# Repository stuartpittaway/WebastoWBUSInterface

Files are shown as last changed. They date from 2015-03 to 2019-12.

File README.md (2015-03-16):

# WebastoWBUSInterface

Hardware circuit and diagram for interfacing to the Webasto WBUS interface from a PC/Arduino

This small circuit allows you to connect a 5 volt device with a serial port to a Webasto Heater which communicates in the WBUS protocol.

The circuit expects you to connect a FT232R USB Serial to TTL interface, or a micro controller such as the Arduino.

Its a http://fritzing.org/home/ circuit/file so you can make a PCB from it if you want (not tested!).

It uses hardly any parts, costs less than £1 (GBP) to make.

Amount 	Part Type 	Properties
1 	Generic female header - 3 pins 	row single; hole size 1.0mm,0.508mm; pin spacing 0.1in (2.54mm); pins 3; form ♀ (female); package THT
3 	NPN-Transistor 	variant variant 2; type NPN (EBC); package TO92 [THT]; part # BC548 NPN
1 	Generic female header - 6 pins 	row single; hole size 1.0mm,0.508mm; pin spacing 0.1in (2.54mm); pins 6; form ♀ (female); package THT; part # FTDI BASIC
1 	Yellow (595nm) LED 	color Yellow (595nm); package 3 mm [THT]; 
1 	PNP-Transistor 	type PNP (CBE); package TO92 [THT]; part # BC557 PNP
4 	10kΩ Resistor 	bands 4; tolerance ±5%; pin spacing 400 mil; resistance 10kΩ; package THT
3 	1kΩ Resistor 	bands 4; tolerance ±5%; pin spacing 400 mil; resistance 1kΩ; package THT

Have fun!

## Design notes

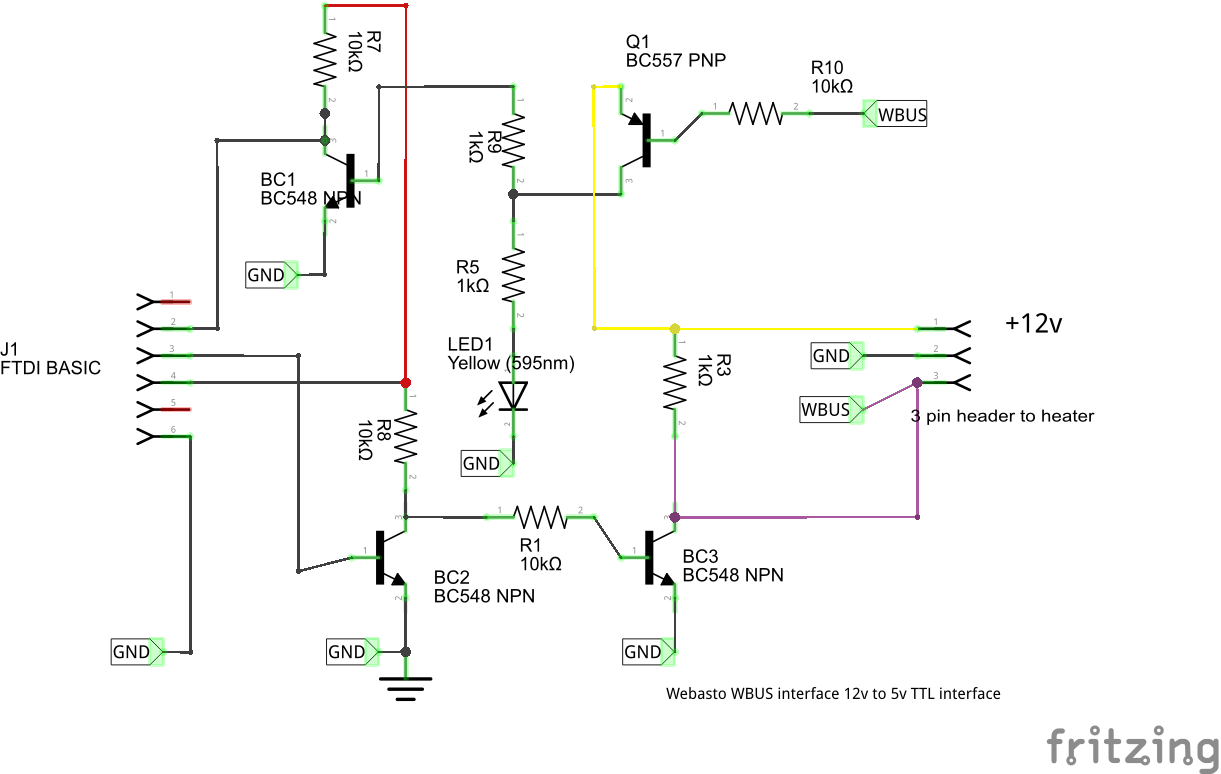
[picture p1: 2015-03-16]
Webasto WBus Arduino Serial Interface mk7_schem.png

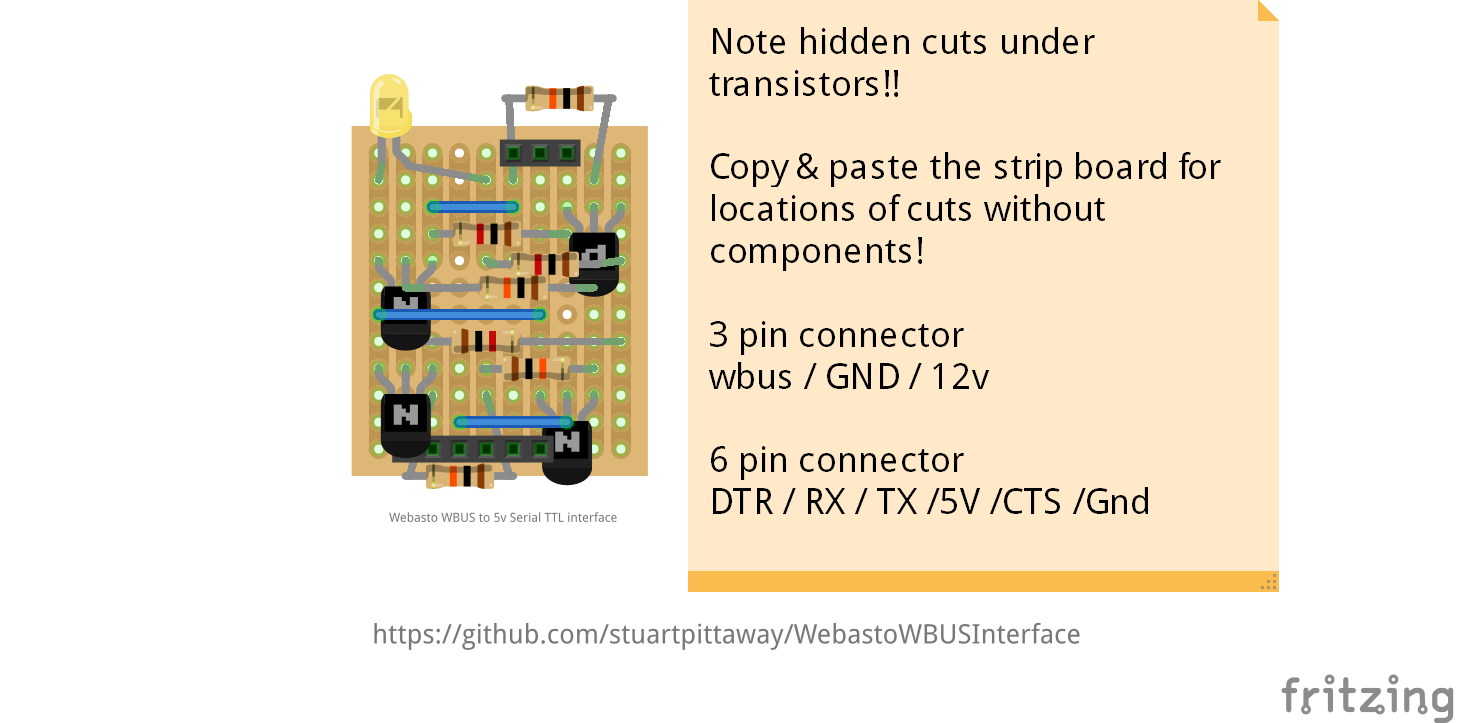
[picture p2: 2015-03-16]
Webasto WBus Arduino Serial Interface mk7_bb.png

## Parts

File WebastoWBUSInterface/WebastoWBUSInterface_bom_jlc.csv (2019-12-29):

Comment | Designator | Footprint | LCSC Part #
LED | D1 | LED_0603_HandSoldering | C72043
S9013 | Q3,Q2,Q1 | SOT-23 | C6749
S9015 | Q4 | SOT-23 | C2149
10K | R1,R8,R10,R7 | R_0805_HandSoldering | C17414
1K | R3,R5,R9 | R_0805_HandSoldering | C17513

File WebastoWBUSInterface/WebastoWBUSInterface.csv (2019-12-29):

Source: | E:\source\WebastoWBUSInterface\WebastoWBUSInterface\WebastoWBUSInterface.sch
Date: | 29/12/2019 22:57:43
Tool: | Eeschema (5.1.0)-1
Generator: | C:\Program Files\KiCad\bin\scripting\plugins/bom_csv_grouped_by_value.py
Component Count: | 14
Individual Components:
Item | Qty | Reference(s) | Value | LibPart | Footprint | Datasheet | JLCPCBPartNumber | Part
 |  | D1 | LED | Device:LED | LEDs:LED_0603_HandSoldering | https://datasheet.lcsc.com/szlcsc/Everlight-Elec-19-217-GHC-YR1S2-3T_C72043.pdf | C72043
 |  | J1 | FTDI Interface | Connector_Generic:Conn_01x06 | Socket_Strips:Socket_Strip_Angled_1x06_Pitch2.54mm | ~
 |  | J2 | WBUS | Connector:Conn_01x03_Female | Connectors_Terminal_Blocks:TerminalBlock_bornier-3_P5.08mm | ~
 |  | Q1 | S9013 | Transistor_BJT:BC548 | TO_SOT_Packages_SMD:SOT-23 | https://datasheet.lcsc.com/szlcsc/Changjiang-Electronics-Tech-CJ-S9015_C2149.pdf | C6749 | S9013
 |  | Q2 | S9013 | Transistor_BJT:BC548 | TO_SOT_Packages_SMD:SOT-23 | https://datasheet.lcsc.com/szlcsc/Changjiang-Electronics-Tech-CJ-S9013_C6749.pdf | C6749 | S9013
 |  | Q3 | S9013 | Transistor_BJT:BC548 | TO_SOT_Packages_SMD:SOT-23 | https://datasheet.lcsc.com/szlcsc/Changjiang-Electronics-Tech-CJ-S9013_C6749.pdf | C6749 | S9013
 |  | Q4 | S9015 | Transistor_BJT:BC557 | TO_SOT_Packages_SMD:SOT-23 | https://datasheet.lcsc.com/szlcsc/Changjiang-Electronics-Tech-CJ-S9015_C2149.pdf | C2149 | S9015
 |  | R1 | 10K | Device:R | Resistors_SMD:R_0805_HandSoldering | https://datasheet.lcsc.com/szlcsc/Uniroyal-Elec-0805W8F1001T5E_C17513.pdf | C17414 | 0805W8F1002T5E
 |  | R3 | 1K | Device:R | Resistors_SMD:R_0805_HandSoldering | https://datasheet.lcsc.com/szlcsc/Uniroyal-Elec-0805W8F1001T5E_C17513.pdf | C17513 | 0805W8F1001T5E
 |  | R5 | 1K | Device:R | Resistors_SMD:R_0805_HandSoldering | https://datasheet.lcsc.com/szlcsc/Uniroyal-Elec-0805W8F1001T5E_C17513.pdf | C17513 | 0805W8F1001T5E
 |  | R7 | 10K | Device:R | Resistors_SMD:R_0805_HandSoldering | https://datasheet.lcsc.com/szlcsc/Uniroyal-Elec-0805W8F1001T5E_C17513.pdf | C17414 | 0805W8F1002T5E
 |  | R8 | 10K | Device:R | Resistors_SMD:R_0805_HandSoldering | https://datasheet.lcsc.com/szlcsc/Uniroyal-Elec-0805W8F1001T5E_C17513.pdf | C17414 | 0805W8F1002T5E
 |  | R9 | 1K | Device:R | Resistors_SMD:R_0805_HandSoldering | https://datasheet.lcsc.com/szlcsc/Uniroyal-Elec-0805W8F1001T5E_C17513.pdf | C17513 | 0805W8F1001T5E
 |  | R10 | 10K | Device:R | Resistors_SMD:R_0805_HandSoldering | https://datasheet.lcsc.com/szlcsc/Uniroyal-Elec-0805W8F1001T5E_C17513.pdf | C17414 | 0805W8F1002T5E
Collated Components:
Item | Qty | Reference(s) | Value | LibPart | Footprint | Datasheet | JLCPCBPartNumber | Part
1 | 1 | D1 | LED | Device:LED | LEDs:LED_0603_HandSoldering | https://datasheet.lcsc.com/szlcsc/Everlight-Elec-19-217-GHC-YR1S2-3T_C72043.pdf | C72043
2 | 1 | J1 | FTDI Interface | Connector_Generic:Conn_01x06 | Socket_Strips:Socket_Strip_Angled_1x06_Pitch2.54mm | ~
3 | 1 | J2 | WBUS | Connector:Conn_01x03_Female | Connectors_Terminal_Blocks:TerminalBlock_bornier-3_P5.08mm | ~
4 | 3 | Q1, Q2, Q3 | S9013 | Transistor_BJT:BC548 | TO_SOT_Packages_SMD:SOT-23 | https://datasheet.lcsc.com/szlcsc/Changjiang-Electronics-Tech-CJ-S9015_C2149.pdf | C6749 | S9013
5 | 1 | Q4 | S9015 | Transistor_BJT:BC557 | TO_SOT_Packages_SMD:SOT-23 | https://datasheet.lcsc.com/szlcsc/Changjiang-Electronics-Tech-CJ-S9015_C2149.pdf | C2149 | S9015
6 | 4 | R1, R7, R8, R10 | 10K | Device:R | Resistors_SMD:R_0805_HandSoldering | https://datasheet.lcsc.com/szlcsc/Uniroyal-Elec-0805W8F1001T5E_C17513.pdf | C17414 | 0805W8F1002T5E
7 | 3 | R3, R5, R9 | 1K | Device:R | Resistors_SMD:R_0805_HandSoldering | https://datasheet.lcsc.com/szlcsc/Uniroyal-Elec-0805W8F1001T5E_C17513.pdf | C17513 | 0805W8F1001T5E

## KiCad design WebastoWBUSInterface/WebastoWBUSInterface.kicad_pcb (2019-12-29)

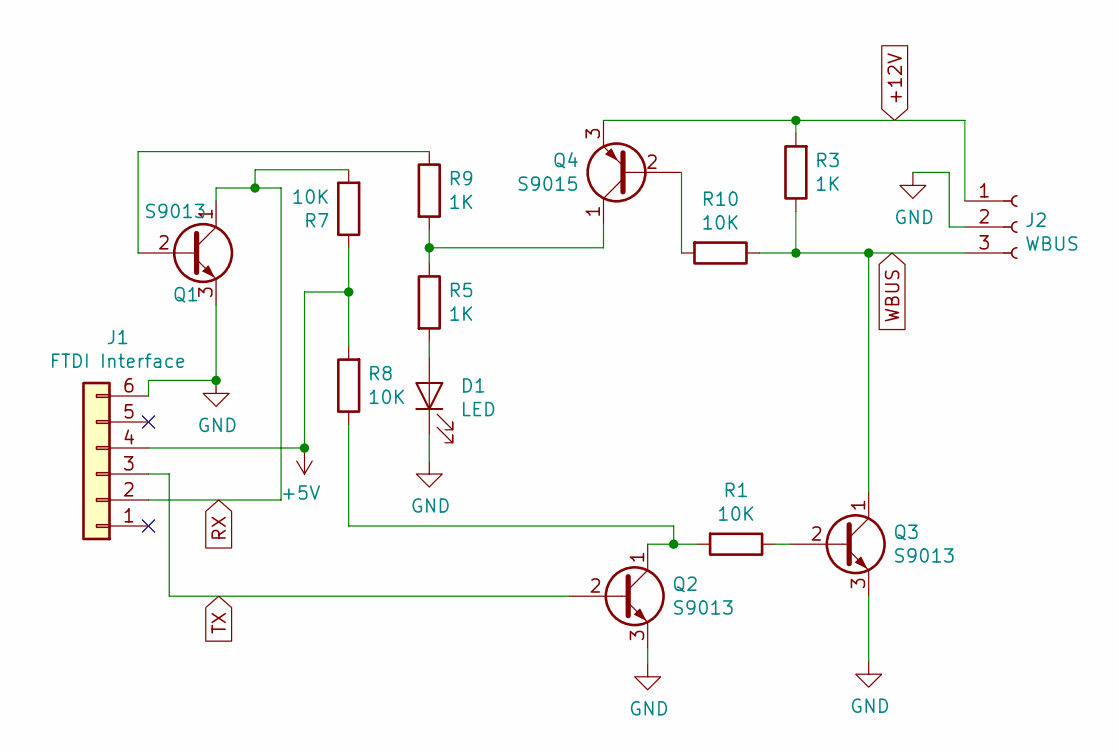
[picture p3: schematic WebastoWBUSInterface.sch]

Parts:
D1: LED; LED_0603_HandSoldering; JLCPCBPartNumber C72043
J1: FTDI Interface; Socket_Strip_Angled_1x06_Pitch2.54mm
J2: WBUS; TerminalBlock_bornier-3_P5.08mm
Q1, Q2, Q3: S9013; SOT-23; Part S9013; JLCPCBPartNumber C6749
Q4: S9015; SOT-23; Part S9015; JLCPCBPartNumber C2149
R1, R7, R8, R10: 10K; R_0805_HandSoldering; Part 0805W8F1002T5E; JLCPCBPartNumber C17414
R3, R5, R9: 1K; R_0805_HandSoldering; Part 0805W8F1001T5E; JLCPCBPartNumber C17513

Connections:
+5V: J1.4, R7.1, R8.2
+12V: J2.1, Q4.3 (E), R3.2
GND: D1.1 (K), J1.6, J2.2, Q1.3 (E), Q2.3 (E), Q3.3 (E)
unnamed: D1.2 (A), R5.2
unnamed: Q1.2 (B), R9.1
unnamed: Q2.1 (C), R1.2, R8.1
unnamed: Q3.2 (B), R1.1
unnamed: Q4.1 (C), R5.1, R9.2
unnamed: Q4.2 (B), R10.2
RX: J1.2, Q1.1 (C), R7.2
TX: J1.3, Q2.2 (B)
WBUS: J2.3, Q3.1 (C), R3.1, R10.1

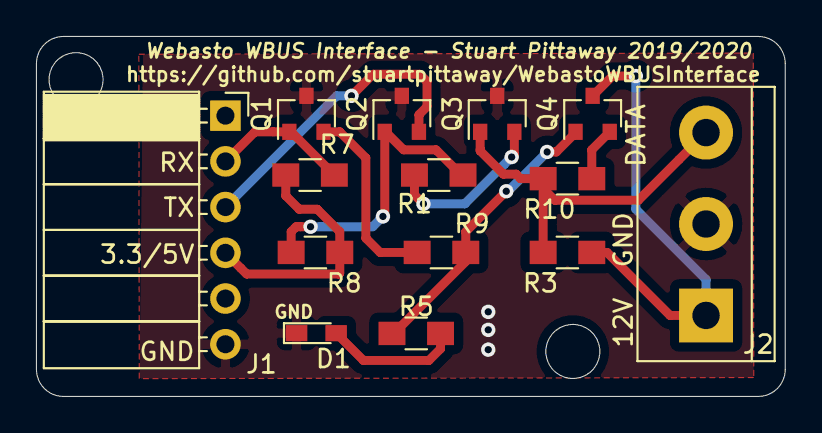
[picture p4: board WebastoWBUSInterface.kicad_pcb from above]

Board: 2 copper layers, 41.6 x 20.0 mm, 14 parts (0 on the bottom side), 12 nets.

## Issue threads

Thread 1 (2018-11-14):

Interface usage

caspervanzoest, 2018-11-14:
Nice work!

I've created this circuit using the example & descriptions,
However, I have a few questions on the usage,
since it is not (yet) working for me.
I am trying to debug what is wrong.

- Should te LED be always on or is it supposed to flash on either (or both?) TX / RX?
- The RX and TX are from the USB serial device point of view, or from the wbus point of view?
   (i.e. Transmit from vbus is recieve on USB)
- Are both 5V and 12V input voltages, or is either one of them output voltage?
- If I put 5v on the TX pin, should the wbus pin have a 12v output?
- if I put 12v on the Wbus pin, should the RX pin have 5v output?

I hope you can help me with answering the questions.
Thanks in advance.

stuartpittaway, 2018-11-14:
Hi, I've not used this circuit for a long time so I don't remember what it should do!  I'll do still have the circuit board so I'll try and take a look tonight.

caspervanzoest, 2018-11-15:
Thank you!
I am looking forward to your answer.

stuartpittaway, 2018-11-15:
Okay, have you built the breadboard circuit or your own following the diagram here?

https://github.com/stuartpittaway/WebastoWBUSInterface/blob/master/Webasto%20WBus%20Arduino%20Serial%20Interface%20mk7_schem.png

There are 3 connections to the heater - WBUS, +12V and GROUND.

There are 4 connections to the FTDI (or computer interface) +5V, GROUND and RX/TX

The LED should flash when data is sent or received.

The circuit is a basic 5v to 12v logic level shifter which converts two wire TX/RX into a single wire WBUS signal.

caspervanzoest, 2018-11-15:
Sounds good, thanks!
I guess I have used a wrong transistor in the circuit, since I did not have a correct one.
I've ordered the specified ones today, so hopefully I can show you the result tomorrow.

Since I am building this for somebody else, and I do not have a Webasto device laying around,
I assume I can test the hardware by putting 5v on the TX pin, and see if the wbus pin gota 12v output?
As well as putting 12v on the w-bus, and seeing if the RX pin is 5v positive, right?

stuartpittaway, 2018-11-15:
> I assume I can test the hardware by putting 5v on the TX pin, and see if the wbus pin got a 12v output?

Yes, but you will need to supply a 12V power to the circuit as well as the 5V

caspervanzoest, 2018-11-15:
> > I assume I can test the hardware by putting 5v on the TX pin, and see if the wbus pin got a 12v output?
>
> Yes, but you will need to supply a 12V power to the circuit as well as the 5V

Got it! Thanks!

Closed 2019-09-10.

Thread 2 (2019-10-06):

WBus to 3.3V

mihai-moldovan, 2019-10-06:
Hi,
this is not actually an issue, but I'm curious what would it take to modify you schematics to connect the WBus line to a 3.3V chip. My project architecture uses this board: https://www.nodemcu.com/index_en.html#fr_54747661d775ef1a3600009e to control the appliance.
One way would be to add a 5v/3.3V TTL converter in front, but I presume there's a simpler way to modify the values of the components in your circuit.

Thanks.

robertobuti, 2019-10-20:
It will work both with 5 or 3V3 power supply, uC side.
bye

mihai-moldovan, 2019-10-21:
Awesome, thanks

Closed 2019-10-21.

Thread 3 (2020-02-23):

commands examples

boelle, 2020-02-23:
Hi

I plan to use this together with a raspberry pi as a pool heater (one of those intex frame pools), its the cheapest option compared to what the pool cost

Where can i look up the commands to send over serial and what i get back?

boelle, 2020-02-23:
so far i found this: https://www.youtube.com/watch?v=6zZjSFef4yA

and an arduino sketch: https://pastebin.com/9jEW030e

out of luck in regards to a python script, so might be "forced" to have an arduino of sorts as the middle man

stuartpittaway, 2020-02-25:
Hello, take a look at my VERY old code

https://github.com/stuartpittaway/WebastoHeaterWBusArduinoInterface

you have to send a start command and then send a "keep awake" command every few seconds afterwards.

stuartpittaway, 2020-02-25:
Hello, take a look at my VERY old code

https://github.com/stuartpittaway/WebastoHeaterWBusArduinoInterface

you have to send a start command and then send a "keep awake" command every few seconds afterwards.

boelle, 2020-03-05:
had a look at the code and i think i will manage

now looking at the kicad work you did, the jlc pcb part is most interesting, did you get boards made? and if so how did they turn out?

and if you have any left overs you know you will not use and want to get rid off i might be interested in

stuartpittaway, 2020-03-05:
Yes the boards work, I also have some blank PCBs spare

boelle, 2020-03-05:
how can i get in contact with you, i did try a google search for an email but no luck

stuartpittaway, 2020-03-05:
Take a look at openenergyforum and drop me a note on therr

boelle, 2020-03-05:
of course "facepalm"

Closed 2020-03-05.

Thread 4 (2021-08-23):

Gerber.zip

MY20-PHEV, 2021-08-23:
Hi Stuart,
First off, thanks for everything you have done on this project. Im looking to get the board done by JLCPCB and wanted them to do the assembly if possible but Im a bit of a noob and I can't see a list of components for the SMD assembly service inside the Gerber.zip ? Am I missing something or is this not available ? Thanks in advance.

stuartpittaway, 2021-08-23:
I hand soldered these boards, many years ago!  I didn't really touch the project since (although its still sitting on a shelf!)

stuartpittaway, 2023-02-14:
Hi @janrunejohansen, as you can see from the repository, I've not touched this project for over 8 years now.  I did get some boards made, but never had chance to use them.

I'd be delighted if you care to fix the issues you have found and submit a pull request to GITHUB.
Thanks.

janrunejohansen, 2023-02-14:
Yeah i get that. I was just letting people know just in case anyone came to order a new batch 🙂 I have fixed mine with inverted inverters, so got what i need for now.

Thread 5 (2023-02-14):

The footprints for the NPN transistors are wrong. Base and Emitter are the wrong way around. So the PCB doesnt work.

stuartpittaway, 2023-02-14:
The footprints for the NPN transistors are wrong. Base and Emitter are the wrong way around. So the PCB doesnt work.

_Originally posted by @janrunejohansen in https://github.com/stuartpittaway/WebastoWBUSInterface/issues/4#issuecomment-1429197757_

janrunejohansen, 2023-02-14:
The 3 NPN's need to rotate one position counter clockwise, and the PNP needs to be inverted to work.

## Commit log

2015-03-16 Updated PCB
    [Webasto WBus Arduino Serial Interface mk7.fzz]
2019-11-24 Recreated design using KICAD for PCB production
    [WebastoWBUSInterface-B_Cu.gbr, WebastoWBUSInterface-B_Mask.gbr, WebastoWBUSInterface-B_Paste.gbr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]
2019-12-29 Larger resistor hole sizes
    [WebastoWBUSInterface-B_Cu.gbr, WebastoWBUSInterface-B_Mask.gbr, WebastoWBUSInterface-B_Paste.gbr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]
2019-12-29 JLCPCB SMD board for full assembly
    [WebastoWBUSInterface-B_Cu.gbr, WebastoWBUSInterface-B_Mask.gbr, WebastoWBUSInterface-B_Paste.gbr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]
